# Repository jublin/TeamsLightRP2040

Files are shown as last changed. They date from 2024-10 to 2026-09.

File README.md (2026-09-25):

# Teams Status Light - Firmware and 3D Models

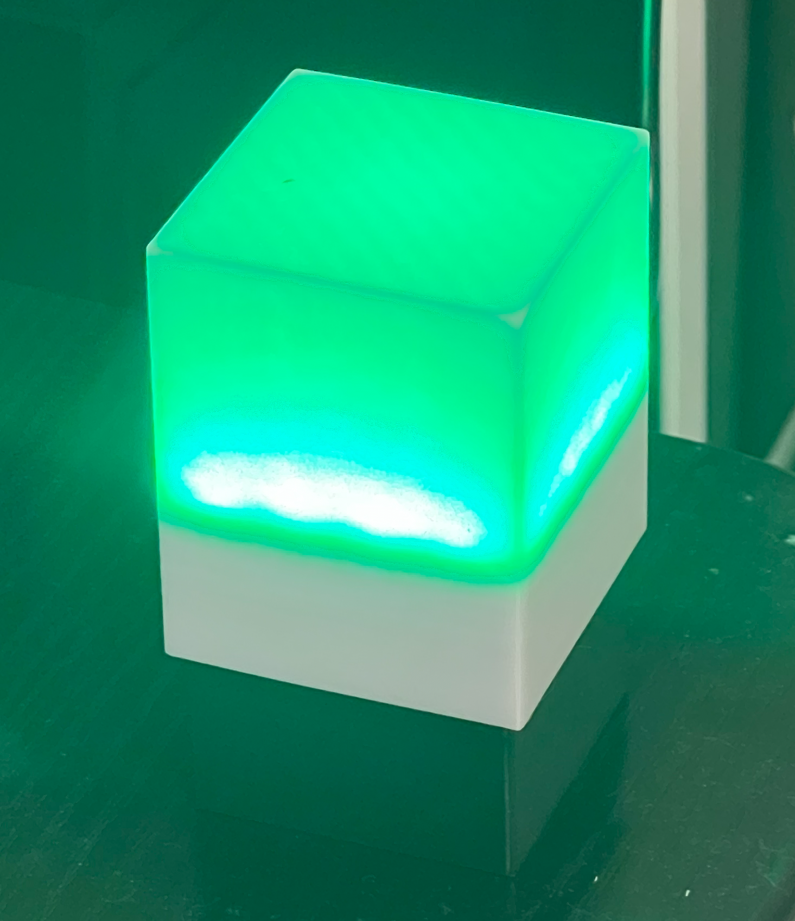
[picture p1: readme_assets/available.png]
Available status shown
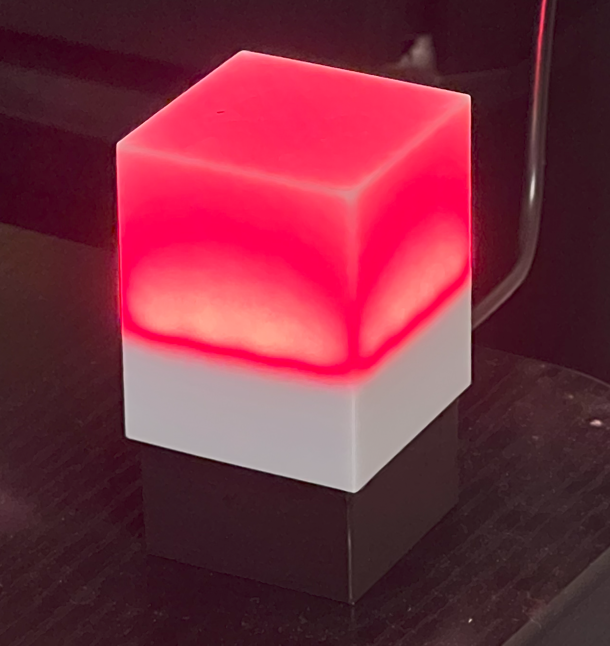
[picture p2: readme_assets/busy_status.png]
Away status shown


## Helper Application for Windows

Code for the TeamsStatusLight WPF application [Here](https://github.com/jublin/TeamsStatusWPF)

## Status notifier features

The firmware supports configurable colors for `available`, `busy`, `away`, `dnd`
(do not disturb), and `offline`. Each preset can be steady, blink, or pulse, with
an adjustable period. Global brightness, lights-off mode, temporary notifications,
and an optional stale-connection timeout are built in. The portable Status Light
companion configures this firmware over the USB protocol below.

Defaults are green, red, amber, purple, and black respectively, all steady.
Brightness starts at 255 to preserve existing RGB behavior; try 64 for a dimmer
desk light. The device starts dark until a status or RGB color arrives. Saved
settings load at startup, but the last displayed status is never restored.

### USB serial protocol (version 1)

Open the port with 8 data bits, no parity, one stop bit, and no hardware flow
control. Enable DTR so replies can be received.

- **9600 or 115200 baud:** existing binary RGB protocol. Send exactly three bytes
  (red, green, blue), without a newline. All byte values remain valid; complete
  triples update the light, and an incomplete triple expires after one second
  without another byte. There are no replies in this mode.
- **57600 baud:** companion-app command protocol. Send the ASCII commands below,
  one per line, terminated by LF or CRLF. Baud is a USB mode selector, not a
  physical transmission speed. Other rates select RGB mode; avoid 1200, which
  the board core reserves for flashing.

Change modes only between messages, after draining the serial buffers. Changing
mode discards an incomplete message and cancels any temporary notification.
For a command-mode reconnect, send a newline and drain its response before `GET`
to clear any abandoned partial line. Do not let two apps own the port at once.

Commands are case-sensitive; status and effect names are lowercase. Numeric
arguments are unsigned decimal integers. A command line has a maximum of 95
characters (excluding CR/LF). Invalid, oversized, or non-ASCII lines return
`ERR command` without changing settings; the parser recovers at the next LF.
Blank lines have no response. Successful commands return `OK`; `SAVE` can return
`ERR storage`. `GET` returns the fields shown below, followed by `OK`.
Send one command and read its complete reply before sending another.

| Command | Behavior |
| --- | --- |
| `GET` | Return protocol version, settings, current status, and stale flag. |
| `STATUS busy` | Select a preset and refresh the status heartbeat. |
| `PRESET busy 255 0 0 pulse 2000` | Set RGB (0–255 each), effect (`steady`, `blink`, `pulse`), and period in milliseconds (100–60000). Changes apply immediately. |
| `BRIGHTNESS 64` | Set global brightness (0–255), including notifications and legacy RGB. |
| `OFF` / `ON` | Hide/show the light while continuing to track status. Status messages do not undo `OFF`. |
| `NOTIFY 0 100 255 blink 500 3000` | Show RGB/effect/period for a duration in milliseconds (1–600000), then return to the latest status. A new notification replaces the old one. |
| `CLEAR` | Cancel the temporary notification. |
| `TIMEOUT 30` | After this many seconds without `STATUS`, a complete RGB triple, or `PING`, display the `offline` preset. Range 0–86400; 0 disables timeout (the default). |
| `PING` | Refresh the heartbeat and clear stale state. Does not create an initial status. |
| `SAVE` | Explicitly persist presets, brightness, and timeout across power cycles. |
| `DEFAULTS` | Restore default presets, brightness, and timeout in memory. Send `SAVE` to persist the reset. |

Example session at **57600 baud** (wait for `OK` after each command):

```text
PRESET busy 255 40 0 steady 1000
PRESET dnd 160 0 255 pulse 2000
BRIGHTNESS 64
TIMEOUT 30
SAVE
STATUS busy
NOTIFY 0 100 255 blink 500 3000
```

With a 30-second timeout, the companion should send `PING` or `STATUS` about
every 10 seconds while its status source is healthy. Configuration commands and
notifications do not refresh the heartbeat. A stale connection overrides a
notification; `OFF` overrides all output. Without a base status, a notification
returns to darkness when it expires. Blink spends half its period on; pulse ramps
linearly from dark to full color and back.

Example `GET` response with default settings after `STATUS busy`:

```text
INFO 1
BRIGHTNESS 255
TIMEOUT 0
ENABLED 1
STATUS busy
STALE 0
PRESET available 0 255 0 steady 1000
PRESET busy 255 0 0 steady 1000
PRESET away 255 160 0 steady 1000
PRESET dnd 180 0 255 steady 1000
PRESET offline 0 0 0 steady 1000
OK
```

`STATUS` reports the underlying status (`none` before the first update, `rgb` for
legacy input), even during a notification, stale state, or lights-off mode.
Settings change in RAM until `SAVE`; save once after editing rather than on every
slider movement. Storage records include a version and checksum, and invalid
records fall back to defaults. PlatformIO uses the Mbed core's KVStore; the
Arduino-Pico core uses its [flash-backed EEPROM](https://arduino-pico.readthedocs.io/en/latest/eeprom.html).
An interrupted flash write can lose saved settings; ordinary status updates never
write flash. Runtime status, notifications, and `OFF` are not persisted.

### Build and checks

```sh
pio run
g++ -std=c++11 -Wall -Wextra -Werror -fsanitize=address,undefined test/notifier.cpp -o /tmp/teamslight-test
/tmp/teamslight-test
python3 test/firmware.py
```

The host check covers fragmented RGB, malformed commands, brightness/effects,
notification expiry, timeout/heartbeat behavior, timer wraparound, and settings
validation. Verify LED colors, USB mode selection, and `SAVE` followed by a power
cycle on the actual board before relying on it.
The firmware-loop check also simulates a stalled USB reader, partial replies,
and storage success/failure while running the real firmware loop.

Both entry points share `Firmware.h` and `StatusLight.h`. For the Arduino IDE,
place `TeamsLight.ino` and those two headers in a folder named `TeamsLight`, select
the Waveshare RP2040 Zero board from the Earle Philhower Arduino-Pico package,
use the default **Pico SDK** USB stack, and install **Adafruit NeoPixel 1.12.3**.
The library is pinned because newer releases use PIO APIs absent from the Mbed
SDK used by this PlatformIO project. `LED_PIN` (default 15) and `LED_COUNT`
(default 16) can be overridden at build time for different wiring.

## Parts needed:

### Round domed enclosure option

The [Blender enclosure generator](3DModels/blender/README.md) creates a 56 mm
diameter, 49.5 mm tall round enclosure with integrated LED mounts, a removable
Pico service bottom, and a dome. It replaces the square printed holders while
retaining the electronics' mounting interfaces. The frame has a stepped inset
seam and the dome uses a hidden three-tab bayonet lock. The script, generated
Blender assembly, STL files, and previews are included.

The LED Matrix I have used can be found on [AliExpress](https://www.aliexpress.us/item/3256806834627585.html) (No affiliate link)

I used this RPi2040 Pico-Zero, also on [AliExpress](https://www.aliexpress.us/item/3256804095235134.html) (No affiliate link)

JST-PH (2.0mm pitch) 0 2 2-pin connector sets (pcb and wire) [Amazon](https://www.amazon.com/gp/product/B09DBHG6NW/)

Feel free to modify as you wish. F360/Step Files included. 

## Flashing

For PlatformIO, the driver for the board must be loaded using [ZaDig](https://zadig.akeo.ie/]) (see [this GitHub isue](https://github.com/platformio/platform-raspberrypi/issues/2#issuecomment-828586398)).

The Arduino sketch uses the same firmware headers as PlatformIO; see the build
instructions above. Board setup instructions are available [here](https://www.waveshare.com/wiki/RP2040-Zero).

You will need to add the board package list to Arduino package manager: https://github.com/earlephilhower/arduino-Pico/releases/download/global/package_rp2040_index.json

## Assembly

Soldier in the 2 connectors on the RPi Pico Zero. You will need the 5V/Gnd, and I chose pins 15 for the LED (other pin isn't used).

Soldier in at least the back header pins. I also put them on each side. 

Insert the Rpi Pico Zero into the bottom part. It will be a tight fit with the pins, but they keep it in place when inserting/removing the USB-C cable. The RP2040 chip will be face down. 

Pico inserted to holder

Solder the VCC/Gnd connector wires to the back of the matrix. Solder the seconds ground with a jumper of any sort. 

Solder the last wire (data in) to the other PH connector wire. 

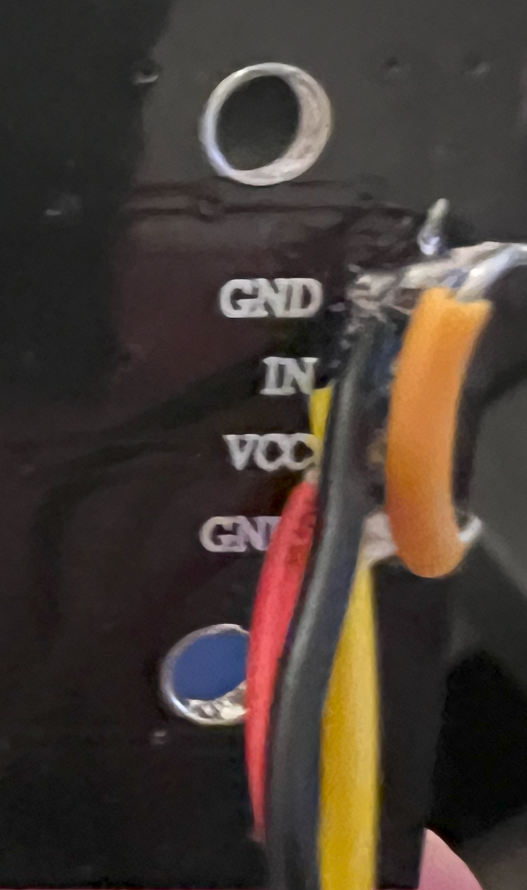
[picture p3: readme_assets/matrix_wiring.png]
Matrix wiring


Add M3x4mm threaded inserts to the four corners in the Pico holder section. 

Feed the PH connectors through the center hole of the matrix holder, and insert them into the connectors on the Pico. 

Leave the matrix unscrewed while screwing in the screws for connecting the matrix and Pico holders.

The leftover wires will be just left pushed into the Pico holder. After that, the matrix can be screwed down with any short 3mm screws. I had some short self-tapping ones [these.](https://www.amazon.com/gp/product/B07DLWSQD5/1)

Matrix screwed to holder

Slide the led cover over. It's just loose enough to allow for an easy slide, but won't fall off. 

Sleeve on

You're done!

Away status shown

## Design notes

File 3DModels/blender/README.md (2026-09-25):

# Round enclosure, revision 3

**56 mm diameter × 49.5 mm high.** This revision mounts the electronics directly
in a purpose-built round enclosure. The original square shells and matrix tray
are not installed. The original STL files remain unmodified.

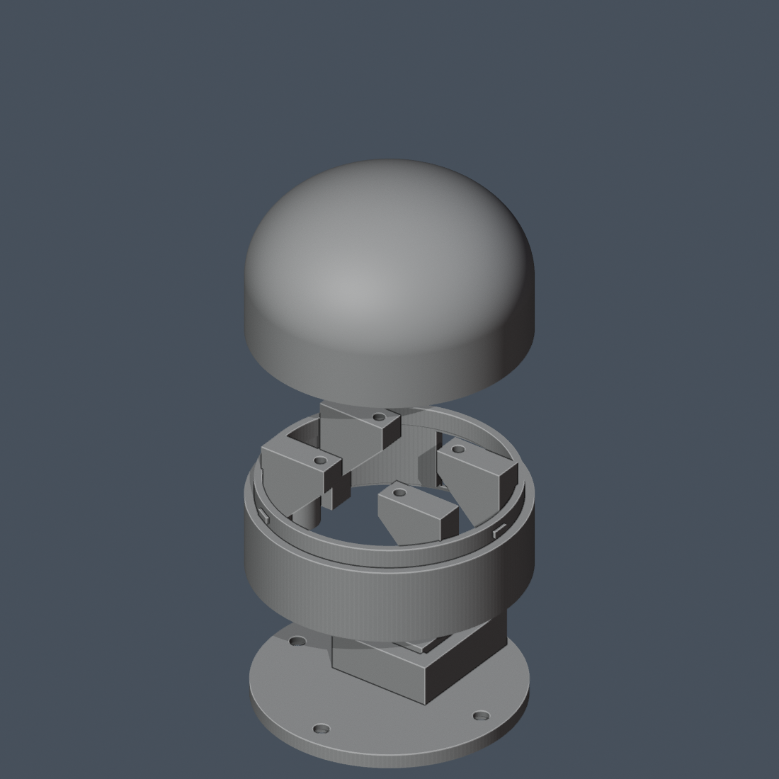
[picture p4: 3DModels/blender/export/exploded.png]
New internal structure


## What changed

- The LED board screws directly to four integrated, sloped brackets. Its original
  19 × 19 mm hole pattern and 2.529 mm pilot diameter are retained. The seats are
  at Z=25 mm, compared with Z=37.3 mm in the first pass.
- The Pico mounts on a removable circular bottom. Only the small board/pin
  retention features are extracted from the original STL. The tall square walls
  and original enclosure's four corner insert towers are discarded.
- The Pico is moved 5.5 mm toward the perimeter. Its original USB opening envelope
  is reproduced in a flat face, with a 3.5 mm exterior recess instead of 13 mm.
  This face moves with the service bottom through an open-bottom slot in the
  frame, so the projecting USB socket does not trap the board during removal.
- Wiring passes through the open center. There is no matrix tray or restrictive
  center hole, and the electronics can be accessed from underneath.
- The bottom uses three peripheral M3 insert bosses. These hold the new enclosure
  together; they do not obstruct the Pico or LED mounting pattern.
- The frame now has a 1 mm inset seam skirt. The service bottom is 1 mm smaller
  than the frame and nests behind that skirt, hiding the small screw-tension gap
  and keeping the parts concentric.
- The dome uses three hidden bayonet tabs. Align the entry slots, press the dome
  down, then twist it 12 degrees counter-clockwise viewed from above to lock it. The slots and grooves are
  cut into the inside of the rim, leaving the outside surface uninterrupted.

The three new prints are a **round frame**, **service bottom with Pico cradle**,
and **translucent dome**. The old printed holders and square diffuser are replaced.

## Generate and check

Tested in Blender 5.2.2, using only its bundled Python modules. From the repository
root:

```sh
blender --background --python-exit-code 1 --python 3DModels/blender/round_dome.py -- --render
blender --background 3DModels/blender/output_v2/round_enclosure.blend --python-exit-code 1 --python 3DModels/blender/check_fit.py
```

You can also open the saved script in Blender's Text Editor and choose **Run
Script**. Keep it in this folder so the original STLs can be found. Command-line
options `--models /path/to/3DModels` and `--output /path/to/destination` override
the defaults. `--render` adds the three previews.

Current output is in **`output_v2/`**:

- `round_enclosure.blend`: assembled model, opening directly to the assembly.
- `round_frame.stl`, `service_bottom.stl`, `round_dome.stl`: separate printable parts.
- `assembled.png`, `interior.png`, `exploded.png`: shape previews.
- `validation.json`: closed-mesh checks, volumes, and dimensions.
- `fit_checks.json`: collision, retention, insertion-clearance and mounting checks.

The `output/` folder contains the superseded first-pass model for comparison.
Do not mix its printed parts with revision 3. Each STL is independently placed
on Z=0 for slicing; use the Blender file to inspect the assembled positions.

Running the generator replaces only its named collection and generated files.
It sets the active scene units to millimetres. Other existing objects remain;
the saved assembly excludes them.

## Hardware and assembly

Reuse the RP2040 Zero, 4×4 LED matrix, JST connectors, wires, and short LED screws.
Three of the original M3×4 mm threaded inserts fit the new service-bottom bosses.
The bottom closure is designed for **three M3×6 mm button-head screws**, with
head diameter at most 6.4 mm and head height at most 1.8 mm. Check your existing
screws; obtain matching screws if necessary.

1. Install the three inserts from the frame's underside, flush with the boss
   faces. The sockets are 4.1 mm diameter, following the original insert bore.
2. Fit the Pico into the service bottom's retention features, in the same
   chip-down orientation as the original. Its USB port faces the nearby edge.
3. Connect the JST wiring while the bottom is accessible. Bring the bottom up
   into the frame, align the USB aperture, and fasten the three bottom screws.
4. Lay the LED board onto the four seats and use the original short self-tapping
   screws. Pilot depth is 4 mm; limit screw projection below the PCB to 3 mm.
   Arrange the wire slack in the open center, away from the screw seats.
5. Align the three dome entry slots with the three frame tabs. Press the dome
   down until its rim seats at Z=16 mm, then twist it 12 degrees
   counter-clockwise viewed from above. To remove it, twist clockwise back to
   the entry-slot position and lift.

The dome is a removable bayonet cover with 0.30 mm radial clearance. Its lock is
internal, so there are no exterior clips or holes. Lift the device by the base;
the bottom, frame and dome can each be removed for servicing.

## Printing and fit limits

Print the frame and bottom in opaque material and the 1.6 mm thick dome in
translucent material. The bracket undersides slope at 45 degrees. Review the
dome roof support/bridging in your slicer. The previews show geometry, not tested
optical diffusion. A small joint test print can help tune `RADIAL_FIT`.

The fit checks verify that the three printed pieces do not overlap, the retained
Pico cradle has not lost material, and the four LED seats and pilot depths are
correct. They also check the base/frame seam, the three bayonet tabs at the
12-degree locked position, and a sampled service-bottom insertion path with the PCB,
projecting USB socket and JST allowances, and assumed electronics
clearance envelopes: 18.3 × 23.5 × 1.59 mm for the Pico PCB above the supports,
17 × 8 × 9 mm for JST connector space, and 35 × 35 × 4 mm above the LED seats.
These envelopes are inferred allowances, **not exact component CAD models**.
Cable molding, solder joints, connector placement, printer tolerances, and the
full assembly motion still need a physical fit test. No physical print test has
been performed.

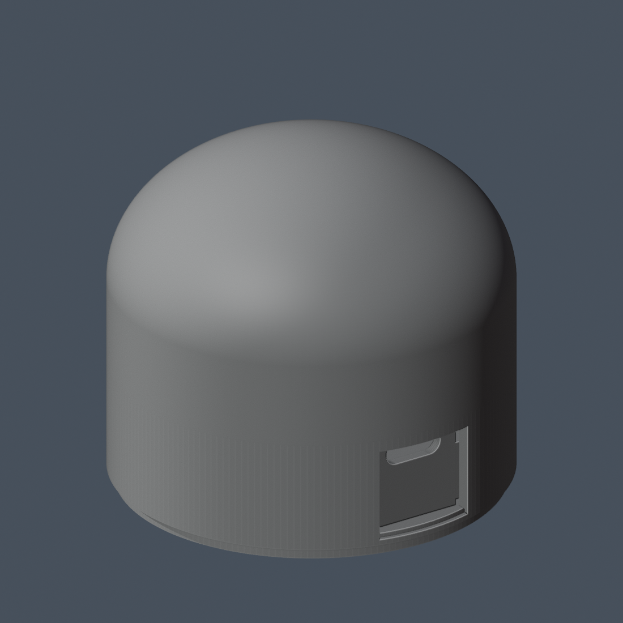
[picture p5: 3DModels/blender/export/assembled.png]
Round enclosure


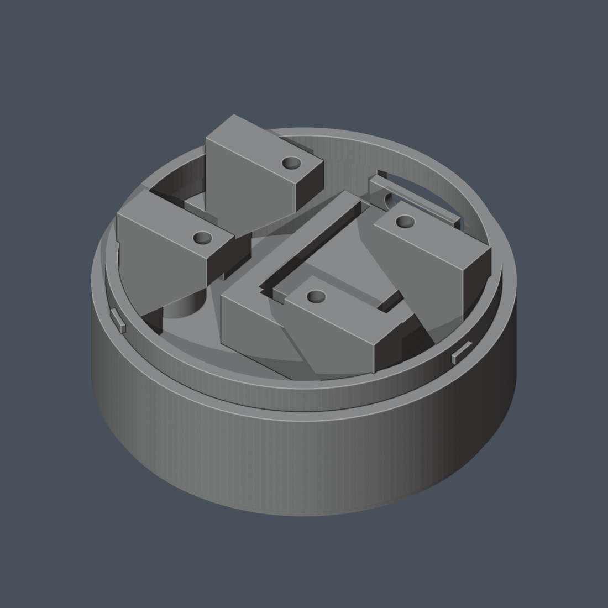
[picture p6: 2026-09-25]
3DModels/blender/export/interior.png

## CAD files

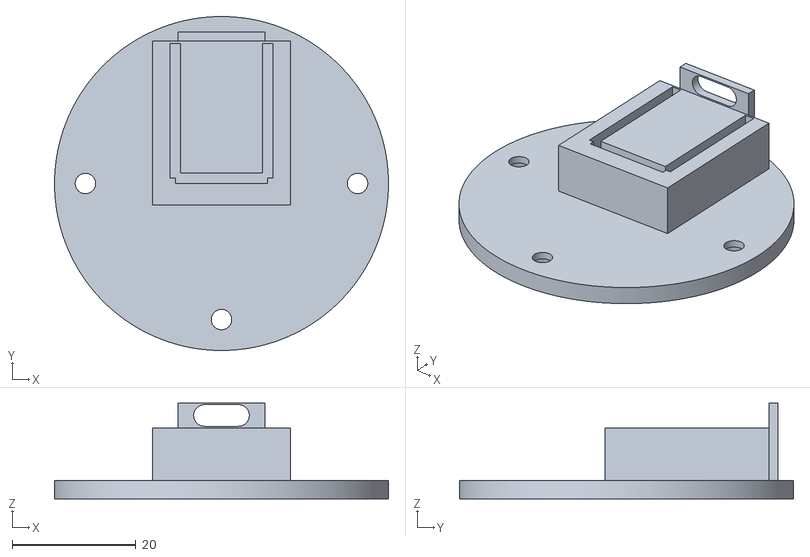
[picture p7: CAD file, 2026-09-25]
3DModels/blender/export/service_bottom.stl
54.0 x 54.0 x 15.5

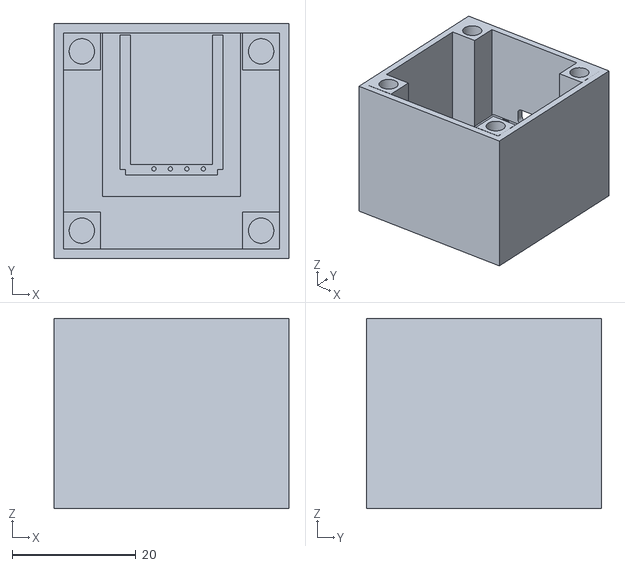
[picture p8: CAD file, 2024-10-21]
3DModels/rpi_2040_zero_bottomv2.stl
38.0 x 38.0 x 30.8

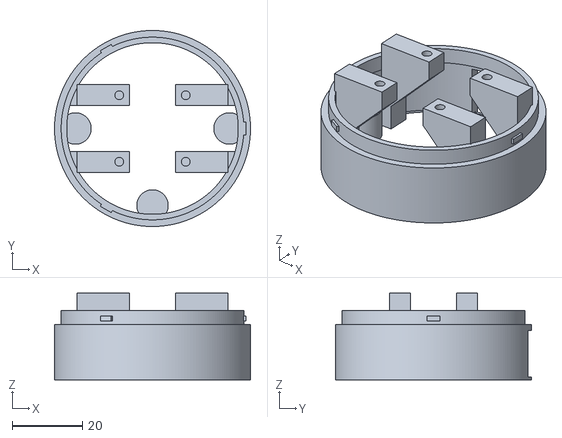
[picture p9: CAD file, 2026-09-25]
3DModels/blender/export/round_frame.stl
56.0 x 56.0 x 24.8

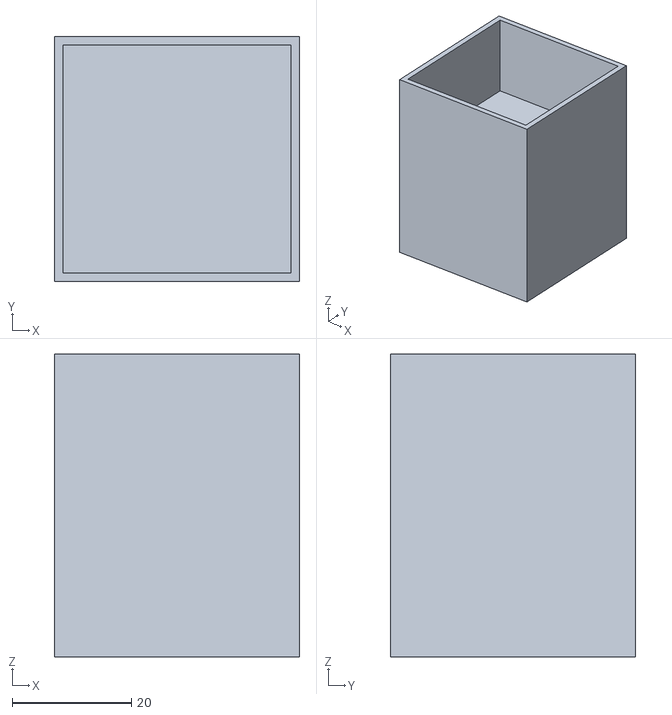
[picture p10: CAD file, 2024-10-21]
3DModels/clear-light-pathv2.stl
41.2 x 41.2 x 50.8

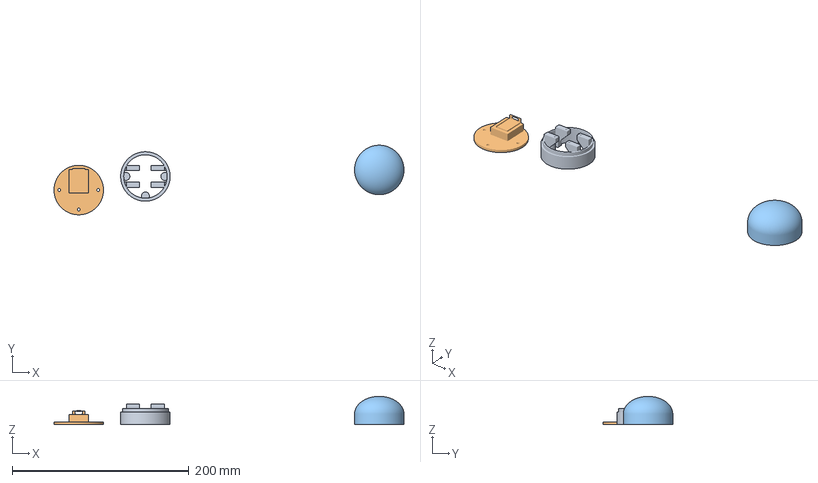
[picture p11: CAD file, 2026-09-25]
3DModels/blender/export/round_dome.3mf
396.1 x 78.8 x 32.0 mm
round_frame.stl
service_bottom.stl
round_dome.stl

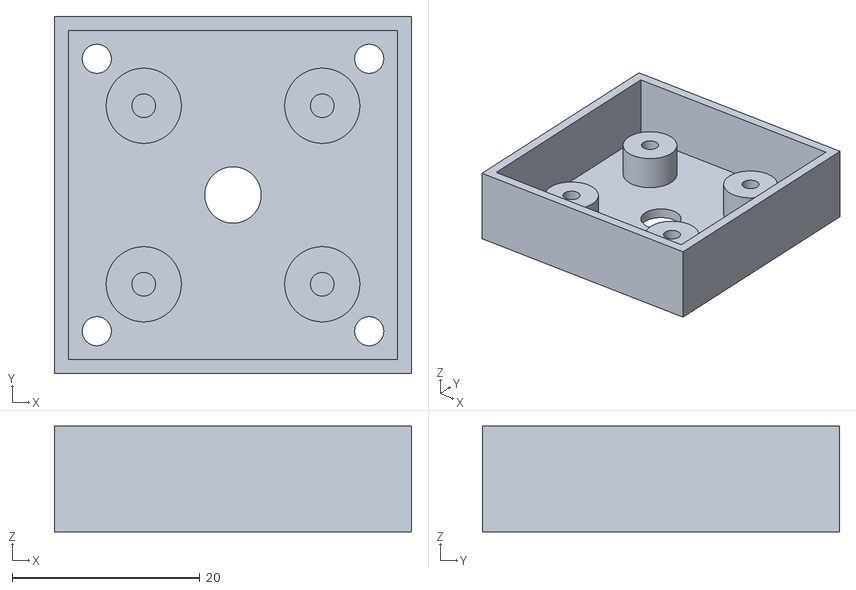
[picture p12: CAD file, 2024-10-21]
3DModels/Matrix_holderv2.stl
38.0 x 38.0 x 11.3

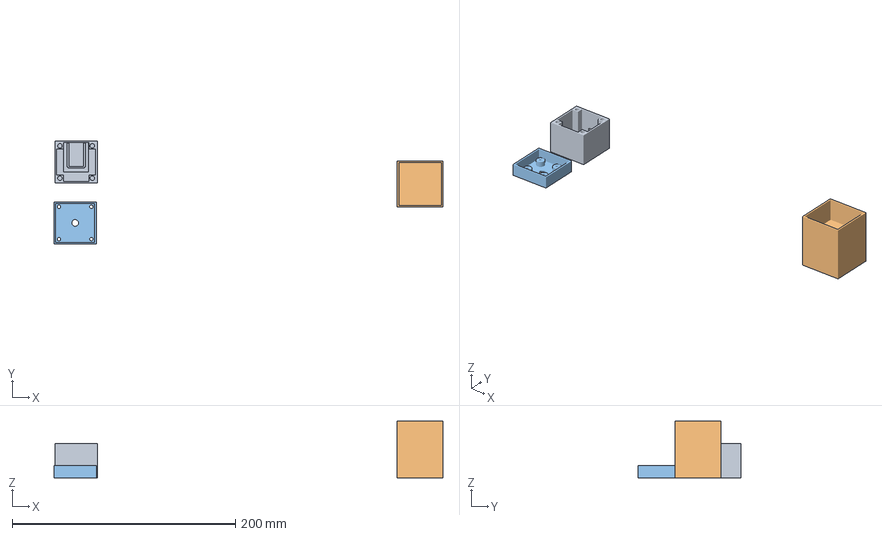
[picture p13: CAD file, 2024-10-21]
3DModels/TeamsStatusLight.3mf
348.8 x 92.6 x 50.8 mm
rpi_2040_zero_bottomv2.stl
clear-light-pathv2.stl
Matrix_holderv2.stl

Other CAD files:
3DModels/TeamsStatusLight.f3d
3DModels/blender/export/round_dome.stl
3DModels/blender/export/round_enclosure.blend

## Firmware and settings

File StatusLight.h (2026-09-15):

#pragma once

#include <stdint.h>
#include <stddef.h>
#include <stdio.h>
#include <string.h>

namespace statuslight {

enum class Result { None, Ok, Error, Get, Save };
enum Effect : uint8_t { Steady, Blink, Pulse };
struct Preset {
    uint16_t periodMs;
    uint8_t red, green, blue, effect;
};
struct Config {
    uint32_t version, timeoutMs;
    Preset presets[5];
    uint8_t brightness, reserved;
    uint32_t checksum;
};
static_assert(sizeof(Config) == 44, "Unexpected config layout");

class Notifier {
public:
    Notifier() { defaults(); }

    void setCommandMode(bool enabled) {
        if (commands_ != enabled) {
            commands_ = enabled;
            length_ = 0;
            invalid_ = false;
            notificationMs_ = 0;
        }
    }

    Result feed(uint8_t byte, uint32_t now) {
        if (!commands_) {
            if (length_ && uint32_t(now - byteAt_) >= 1000) length_ = 0;
            byteAt_ = now;
            line_[length_++] = static_cast<char>(byte);
            if (length_ == 3) {
                raw_ = {1000, uint8_t(line_[0]), uint8_t(line_[1]), uint8_t(line_[2]), Steady};
                status_ = -1;
                haveStatus_ = true;
                statusAt_ = lastSeen_ = now;
                stale_ = false;
                length_ = 0;
            }
            return Result::None;
        }
        if (byte == '\n') {
            line_[length_] = 0;
            Result result = invalid_ ? Result::Error : command(now);
            length_ = 0;
            invalid_ = false;
            return result;
        }
        if (byte == '\r') return Result::None;
        if ((byte < 32 && byte != '\t') || byte > 126 || length_ == sizeof(line_) - 1)
            invalid_ = true;
        else if (!invalid_) line_[length_++] = static_cast<char>(byte);
        return Result::None;
    }

    uint32_t color(uint32_t now) {
        if (notificationMs_ && uint32_t(now - notificationAt_) >= notificationMs_) notificationMs_ = 0;
        if (haveStatus_ && config_.timeoutMs && uint32_t(now - lastSeen_) >= config_.timeoutMs) stale_ = true;
        if (!enabled_) return 0;
        // A stale connection overrides even a still-running notification.
        const Preset *preset = nullptr;
        uint32_t start = statusAt_;
        if (stale_) {
            preset = &config_.presets[4];
            start = lastSeen_ + config_.timeoutMs;
        } else if (notificationMs_ && uint32_t(now - notificationAt_) < notificationMs_) {
            preset = &notification_;
            start = notificationAt_;
        } else if (haveStatus_) {
            preset = status_ < 0 ? &raw_ : &config_.presets[status_];
        }
        if (!preset) return 0;
        uint32_t level = 255, maximum = 255;
        uint32_t phase = uint32_t(now - start) % preset->periodMs;
        if (preset->effect == Blink) level = phase < preset->periodMs / 2 ? 255 : 0;
        if (preset->effect == Pulse) {
            uint32_t half = preset->periodMs / 2;
            level = phase <= half ? phase : preset->periodMs - phase;
            maximum = phase <= half ? half : preset->periodMs - half;
        }
        uint32_t scale = level * config_.brightness;
        uint32_t divisor = maximum * 255;
        return ((preset->red * scale / divisor) << 16) |
               ((preset->green * scale / divisor) << 8) | (preset->blue * scale / divisor);
    }

    Config snapshot() const {
        Config saved = config_;
        saved.checksum = checksum(saved);
        return saved;
    }

    bool restore(const Config &saved) {
        if (saved.version != 1 || saved.reserved != 0 || saved.timeoutMs > 86400000 ||
            saved.checksum != checksum(saved)) return false;
        for (const auto &p : saved.presets)
            if (p.effect > Pulse || p.periodMs < 100 || p.periodMs > 60000) return false;
        config_ = saved;
        return true;
    }

    void describe(char *out, size_t size, uint32_t now) const {
        int used = snprintf(out, size, "INFO 1\nBRIGHTNESS %u\nTIMEOUT %lu\nENABLED %u\nSTATUS %s\nSTALE %u\n",
            config_.brightness, static_cast<unsigned long>(config_.timeoutMs / 1000), enabled_,
            !haveStatus_ ? "none" : status_ < 0 ? "rgb" : names()[status_],
            stale_ || (haveStatus_ && config_.timeoutMs && uint32_t(now - lastSeen_) >= config_.timeoutMs));
        for (int i = 0; i < 5 && used >= 0 && size_t(used) < size; ++i) {
            const Preset &p = config_.presets[i];
            used += snprintf(out + used, size - used, "PRESET %s %u %u %u %s %u\n", names()[i],
                p.red, p.green, p.blue, effects()[p.effect], p.periodMs);
        }
    }

private:
    Config config_{};
    Preset raw_{1000, 0, 0, 0, Steady}, notification_{1000, 0, 0, 0, Steady};
    bool commands_ = false, enabled_ = true, haveStatus_ = false, invalid_ = false, stale_ = false;
    int status_ = -1;
    uint32_t statusAt_ = 0, lastSeen_ = 0, notificationAt_ = 0, notificationMs_ = 0, byteAt_ = 0;
    char line_[96]{};
    size_t length_ = 0;
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

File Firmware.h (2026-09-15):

#pragma once

#include <Arduino.h>
#include <Adafruit_NeoPixel.h>
#include "StatusLight.h"

#if defined(ARDUINO_ARCH_MBED)
#include <kvstore_global_api.h>
#include <USB/PluggableUSBSerial.h>
#else
#include <EEPROM.h>
#include <tusb.h>
#endif

#ifndef LED_PIN
#define LED_PIN 15
#endif
#ifndef LED_COUNT
#define LED_COUNT 16
#endif

statuslight::Notifier notifier;
Adafruit_NeoPixel matrix(LED_COUNT, LED_PIN, NEO_GRB + NEO_KHZ800);

bool saveSettings() {
    const statuslight::Config saved = notifier.snapshot();
#if defined(ARDUINO_ARCH_MBED)
    return kv_set("/kv/statuslight", &saved, sizeof saved, 0) == 0;
#else
    EEPROM.put(0, saved);
    return EEPROM.commit();
#endif
}

void setup() {
    matrix.begin();
    matrix.clear();
    matrix.show();
    Serial.begin(115200);
    statuslight::Config saved{};
#if defined(ARDUINO_ARCH_MBED)
    size_t actual = 0;
    if (kv_get("/kv/statuslight", &saved, sizeof saved, &actual) == 0 && actual == sizeof saved)
        notifier.restore(saved);
#else
    EEPROM.begin(256);
    EEPROM.get(0, saved);
    notifier.restore(saved);
#endif
}

void loop() {
    static char reply[512];
    static uint32_t replySize = 0, sent = 0;
    static bool previousMode = false;
    // USB baud selects the protocol; 1200 is reserved for flashing.
#if defined(ARDUINO_ARCH_MBED)
    bool commandMode = Serial.baud() == 57600;
#else
    cdc_line_coding_t coding;
    tud_cdc_get_line_coding(&coding);
    bool commandMode = coding.bit_rate == 57600;
#endif
    if (commandMode != previousMode) replySize = sent = 0;
    previousMode = commandMode;
    notifier.setCommandMode(commandMode);
    // Bound each batch so serial floods cannot starve animation and timeout checks.
    for (int i = 0; i < 64 && !replySize && Serial.available(); ++i) {
        statuslight::Result result = notifier.feed(uint8_t(Serial.read()), millis());
        switch (result) {
        case statuslight::Result::Save:
            strcpy(reply, saveSettings() ? "OK\n" : "ERR storage\n");
            break;
        case statuslight::Result::Get:
            notifier.describe(reply, sizeof(reply) - 4, millis());
            strcat(reply, "OK\n");
            break;
        case statuslight::Result::Ok: strcpy(reply, "OK\n"); break;
        case statuslight::Result::Error: strcpy(reply, "ERR command\n"); break;
        case statuslight::Result::None: continue;
        }
        replySize = strlen(reply);
    }
    // Keep one reply in flight; a host that stops reading must not freeze the light.
    if (replySize) {
        uint32_t written = 0;
#if defined(ARDUINO_ARCH_MBED)
        _SerialUSB.send_nb(reinterpret_cast<uint8_t *>(reply + sent), replySize - sent, &written);
#else
        int available = Serial.availableForWrite();
        if (available > 0) {
            uint32_t count = replySize - sent;
            if (count > uint32_t(available)) count = uint32_t(available);
            written = Serial.write(reinterpret_cast<uint8_t *>(reply + sent), count);
        }
#endif
        sent += written;
        if (sent == replySize) replySize = sent = 0;
    }
    static uint32_t lastFrame = 0, previousColor = 0;
    uint32_t now = millis();
    if (uint32_t(now - lastFrame) < 10) return;
    lastFrame = now;
    uint32_t color = notifier.color(now);
    if (color != previousColor) {
        matrix.fill(color);
        matrix.show();
        previousColor = color;
    }
}

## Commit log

2024-10-21 Update readme, add 3mf/f3d files
    [Matrix_holderv2.stl, TeamsStatusLight.3mf, TeamsStatusLight.f3d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]
2026-09-25 Add domed v2 model for printing
    [round_dome.3mf, round_dome.stl, round_enclosure.blend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]
2026-09-25 update model to have more seamless look
    [round_dome.stl, round_enclosure.blend, round_frame.stl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]
